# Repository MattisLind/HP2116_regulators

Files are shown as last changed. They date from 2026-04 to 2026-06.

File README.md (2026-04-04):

# HP2116_regulators
A project to create replicas of the two voltage regulator boards of the HP2116.

Unfortunately my HP 2116B which I was able to rescue from destruction in the fall of 2025 was missing not just two logic boards (of which one I was able to buy on Ebay later) but also two very important small regulator boards. The purpose of these two boards is to control the generation of all the voltages needed by the computer.

Missing regulators

Finding the exact boards will probably take quite long time if at all possible.

A fellow collector took photos of the boards in his HP 2116C machine. They are very similar except for the memorys regulator not supplying a 32V so those components are not populated.

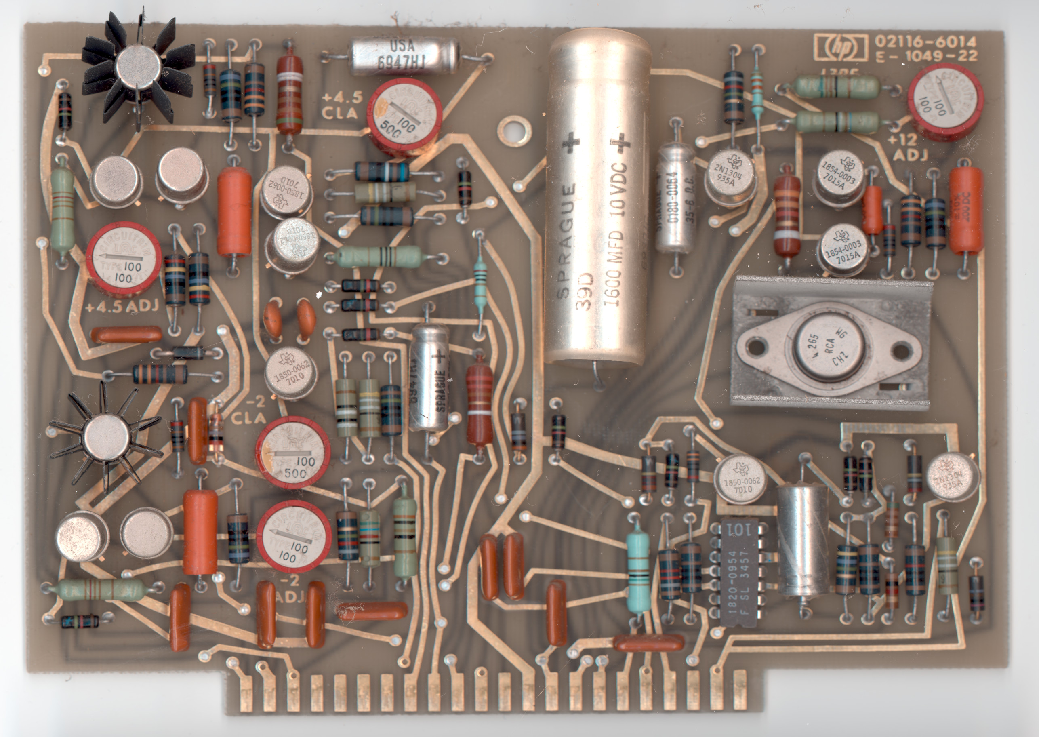
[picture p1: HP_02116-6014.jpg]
Logic regulator

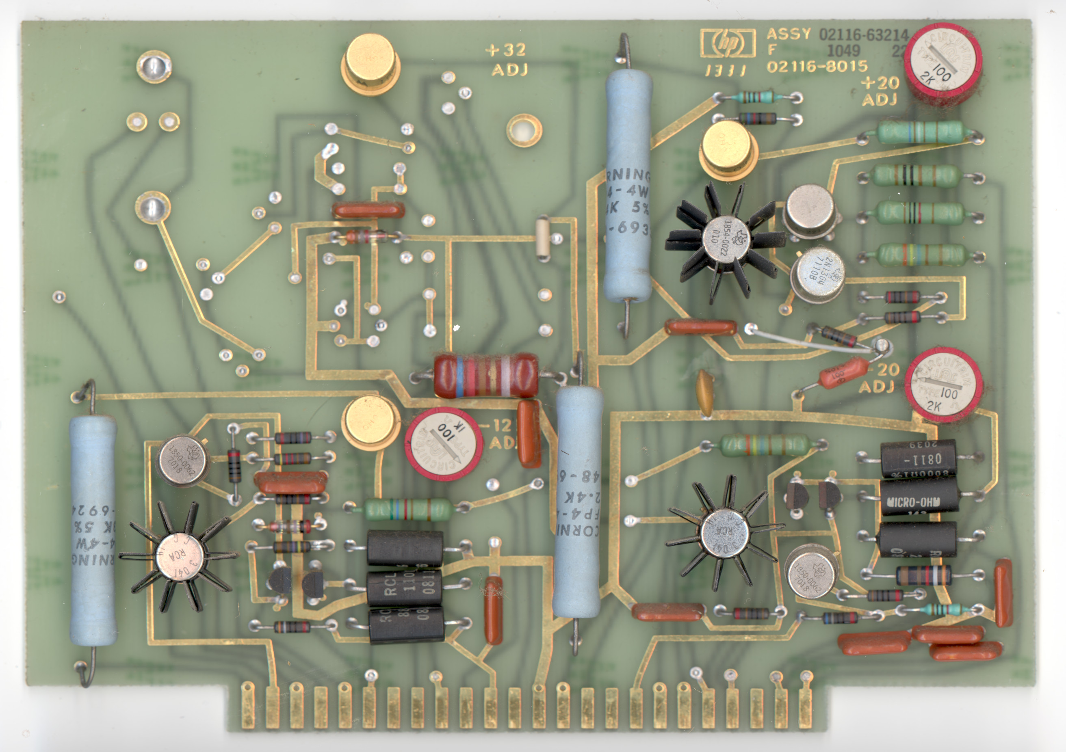
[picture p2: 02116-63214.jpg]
Memory regulator


He also took some measurements of the boards

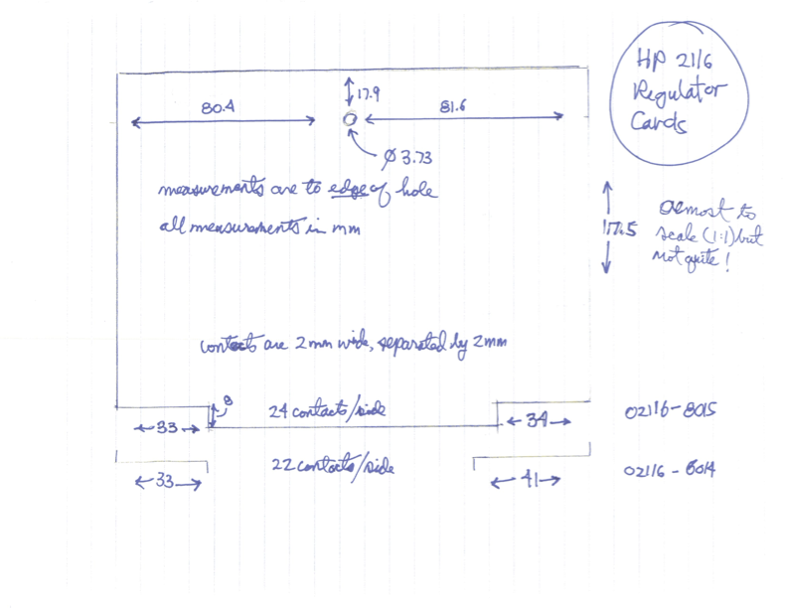
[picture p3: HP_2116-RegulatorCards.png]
Measurments


Thank you Jack! With this I will be able to create boards that fit the machine correctly.

I will be facing a number of problems when doing this. For example there are extensive use of really old Germanium transistors used. The reason for this is partly because of the low Vbe forward voltage. These transistors are used in the current sense circuit basically sitting with the B and E over the current sense resistor. The start to conduct over 0.2V and thus limiting or shutting down the power supply if there are excess current. This circuit with these specifcations wouldn't work with Silicon transistors.

Then the Logic Regulator board are using the Fairchild CTL chip family for logic functions and sequencing of the voltages in the power supply. I thought about replacing it with a corresponding TTL circuit but then the problem is that I don't really now how the TTL circuit react when low voltages are used. I.e. when the power supply is starting up. CTL is basically emitter coupled logic and I came to the conclusion that it would be possible to replicate the functionality using discrete NPN and PNP transistors. Tieing together the emitters of PNP transistors creates AND gates while tieing togther emitters of NPN transistors creates OR gates.

I simulated this design in LTSpice and came to the conclusion that it will likely work as the original circuit using the integrated CTL chip.

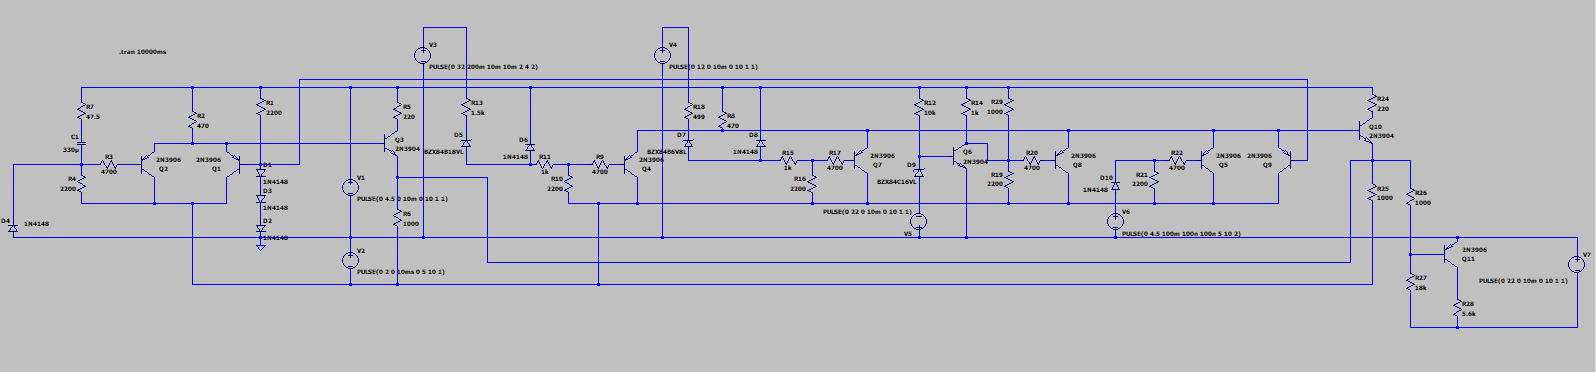
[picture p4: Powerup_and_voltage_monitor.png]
LTSpice simulation


The waveforms of the power monitor

Green is the simulated +32V. Delayed and then goes out after about 2 seconds. Blue is the +12V that power up slowly. Red is the even slower -22V. The cyan signal is the 4.5V PSO signal that tells is there is a overheating condition. The resulting signal is the violet. It enables the -12V regulator when low and shuts it down when grounded. It looks like the logic is working.

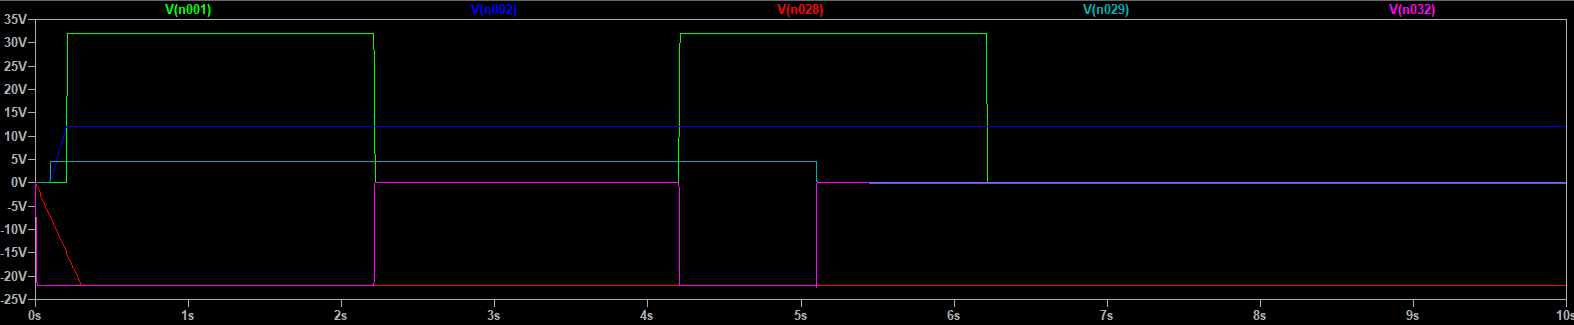
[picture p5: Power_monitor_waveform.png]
Waveforms


In the picture below green is the signal to the -12V supply and the blue is the 4.5V power line.

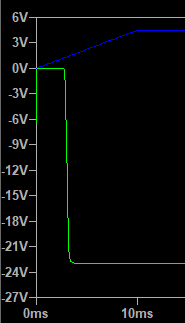
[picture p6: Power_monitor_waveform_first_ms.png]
Waveforms first few milliseconds


Here is the schematic for the logic regulator.

Logic regulator schematic

And this is the memory regulator schematic.

Memory regulator schematic

At this point I have started to procure components. I managed to find the 2N1304 and 2N1305 germanium transistors from a vendor in the UK and the same company also had the 2N4044 matched pairs so now all the small resistors, zeners and caps need to be ordered and then I can start laying out the PCB. Care has to be taken so there is room for the heatsinks on the TO5. Both boards have a TO66 power transistor where the exact match is hard to find. I think a NPN TIP41 should be just fine since this just a simple emitter follower output stage to increase the drive power.

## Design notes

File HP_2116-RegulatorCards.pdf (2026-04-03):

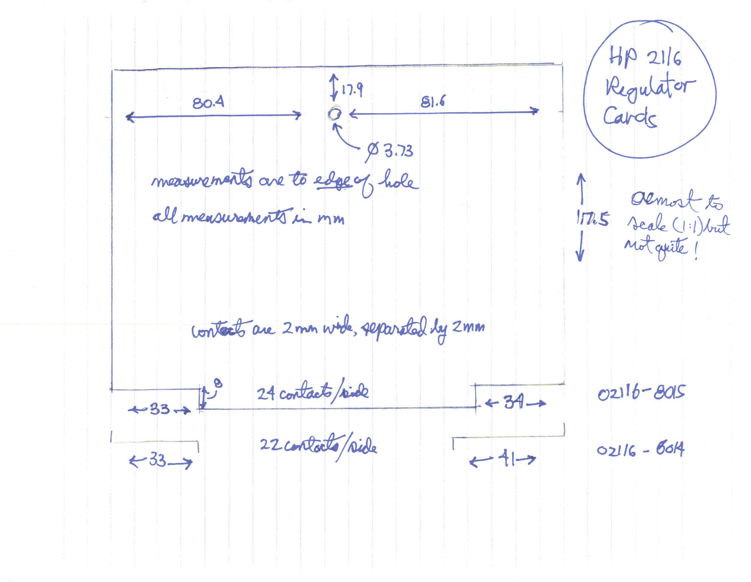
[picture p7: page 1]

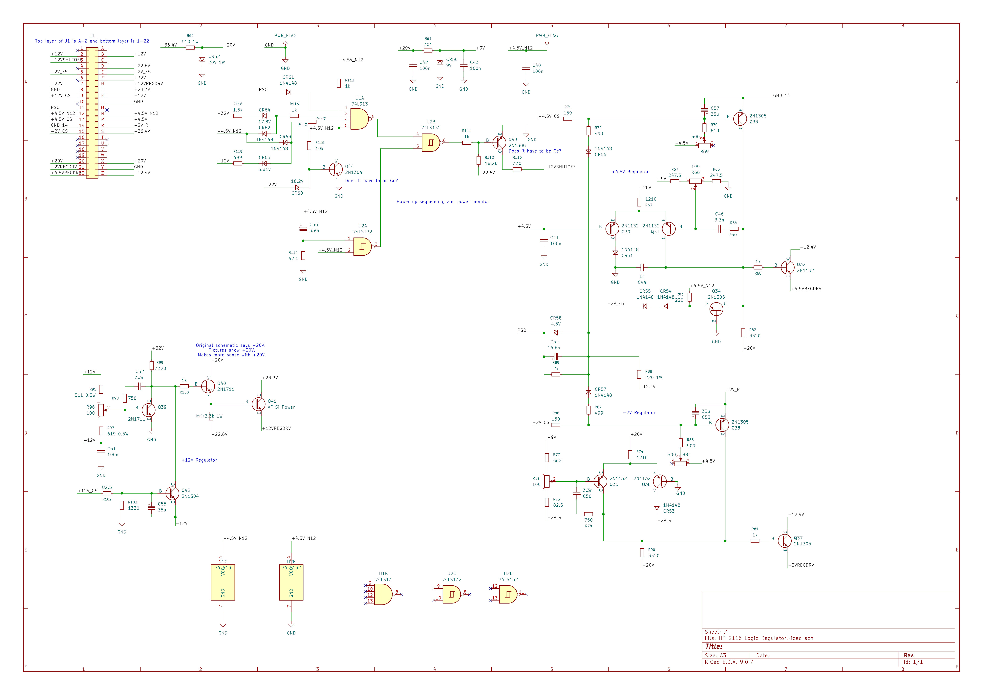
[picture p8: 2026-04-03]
HP_2116_Logic_Regulator/HP_2116_Logic_Regulator.jpg

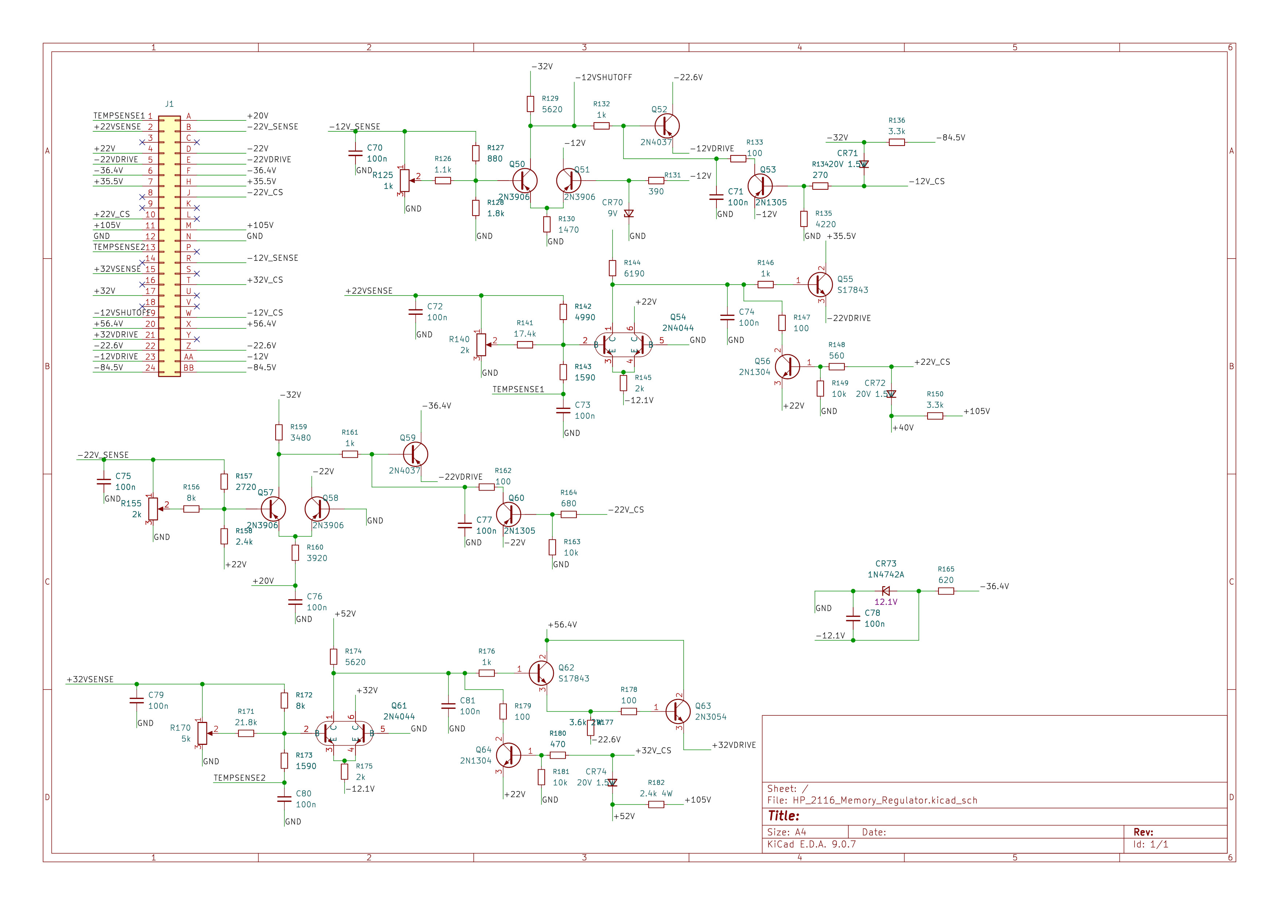
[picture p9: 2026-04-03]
HP_2116_Memory_Regulator/HP_2116_Memory_Regulator.jpg

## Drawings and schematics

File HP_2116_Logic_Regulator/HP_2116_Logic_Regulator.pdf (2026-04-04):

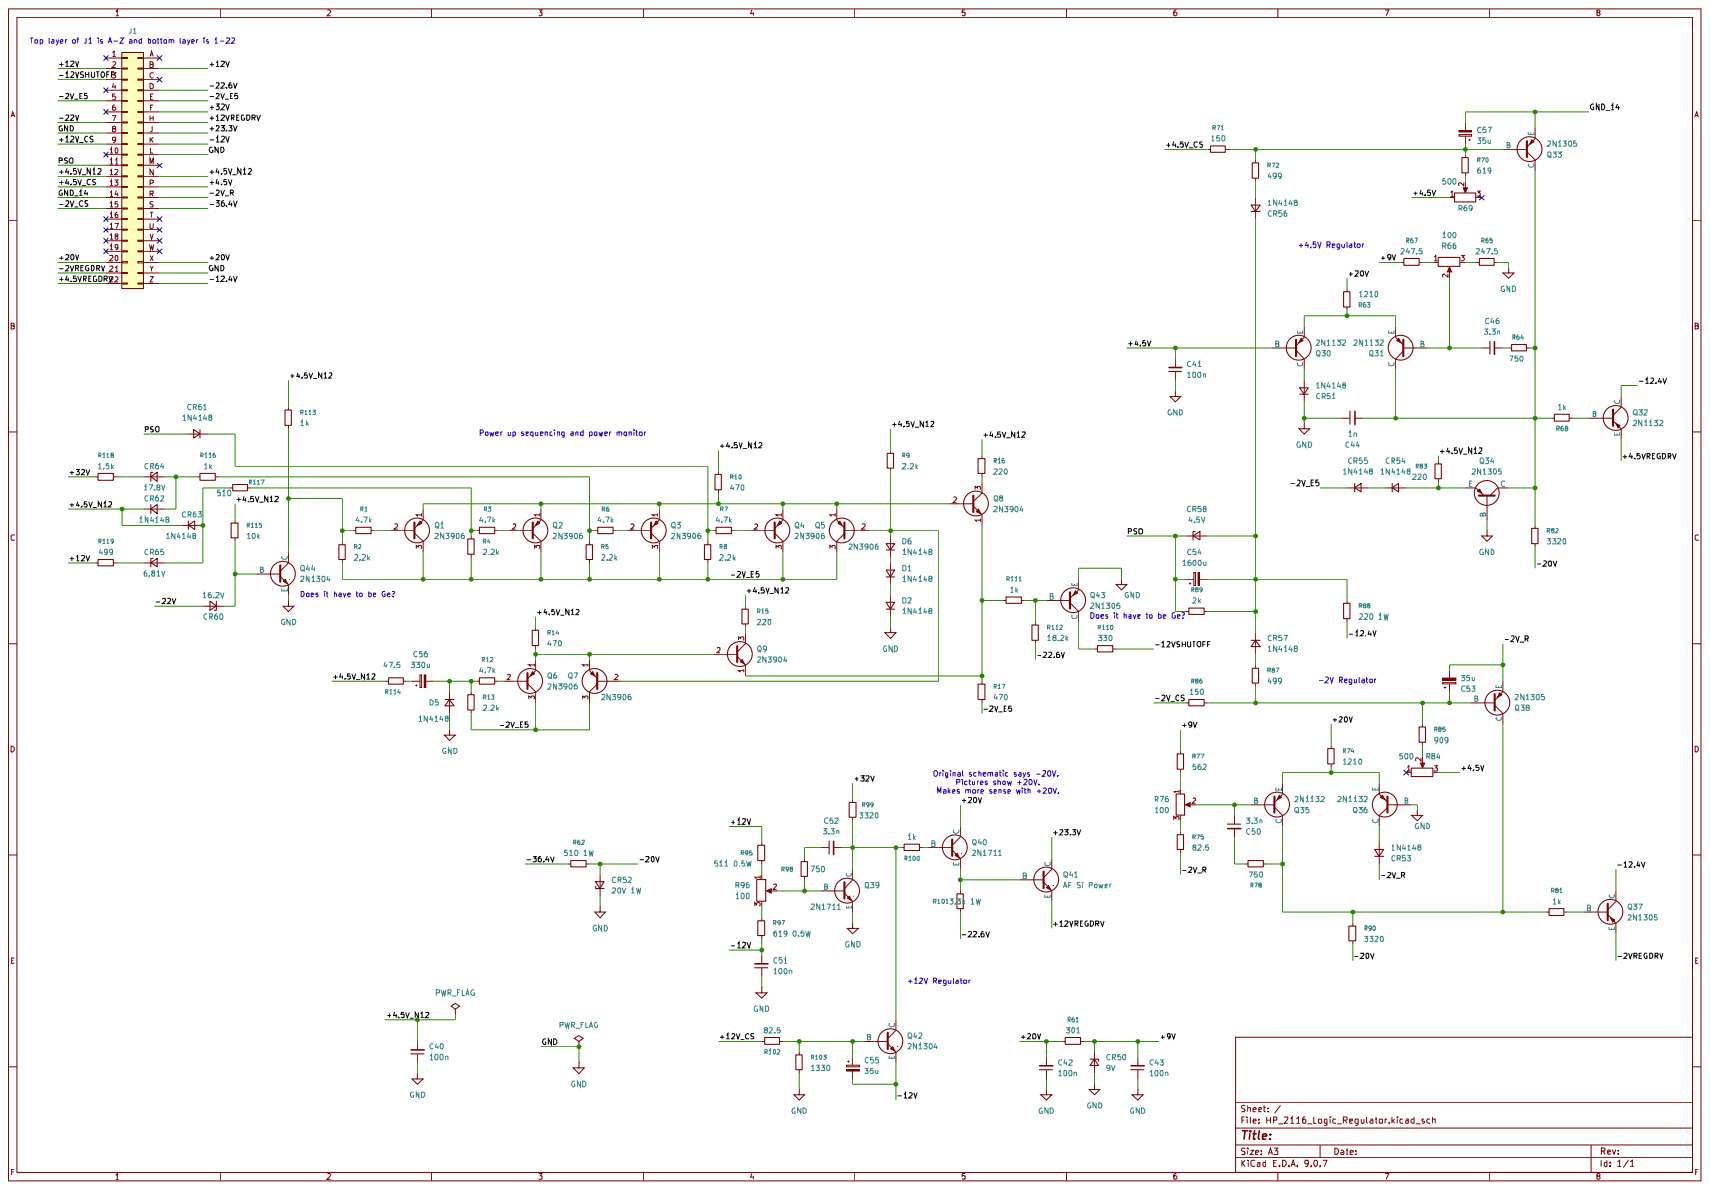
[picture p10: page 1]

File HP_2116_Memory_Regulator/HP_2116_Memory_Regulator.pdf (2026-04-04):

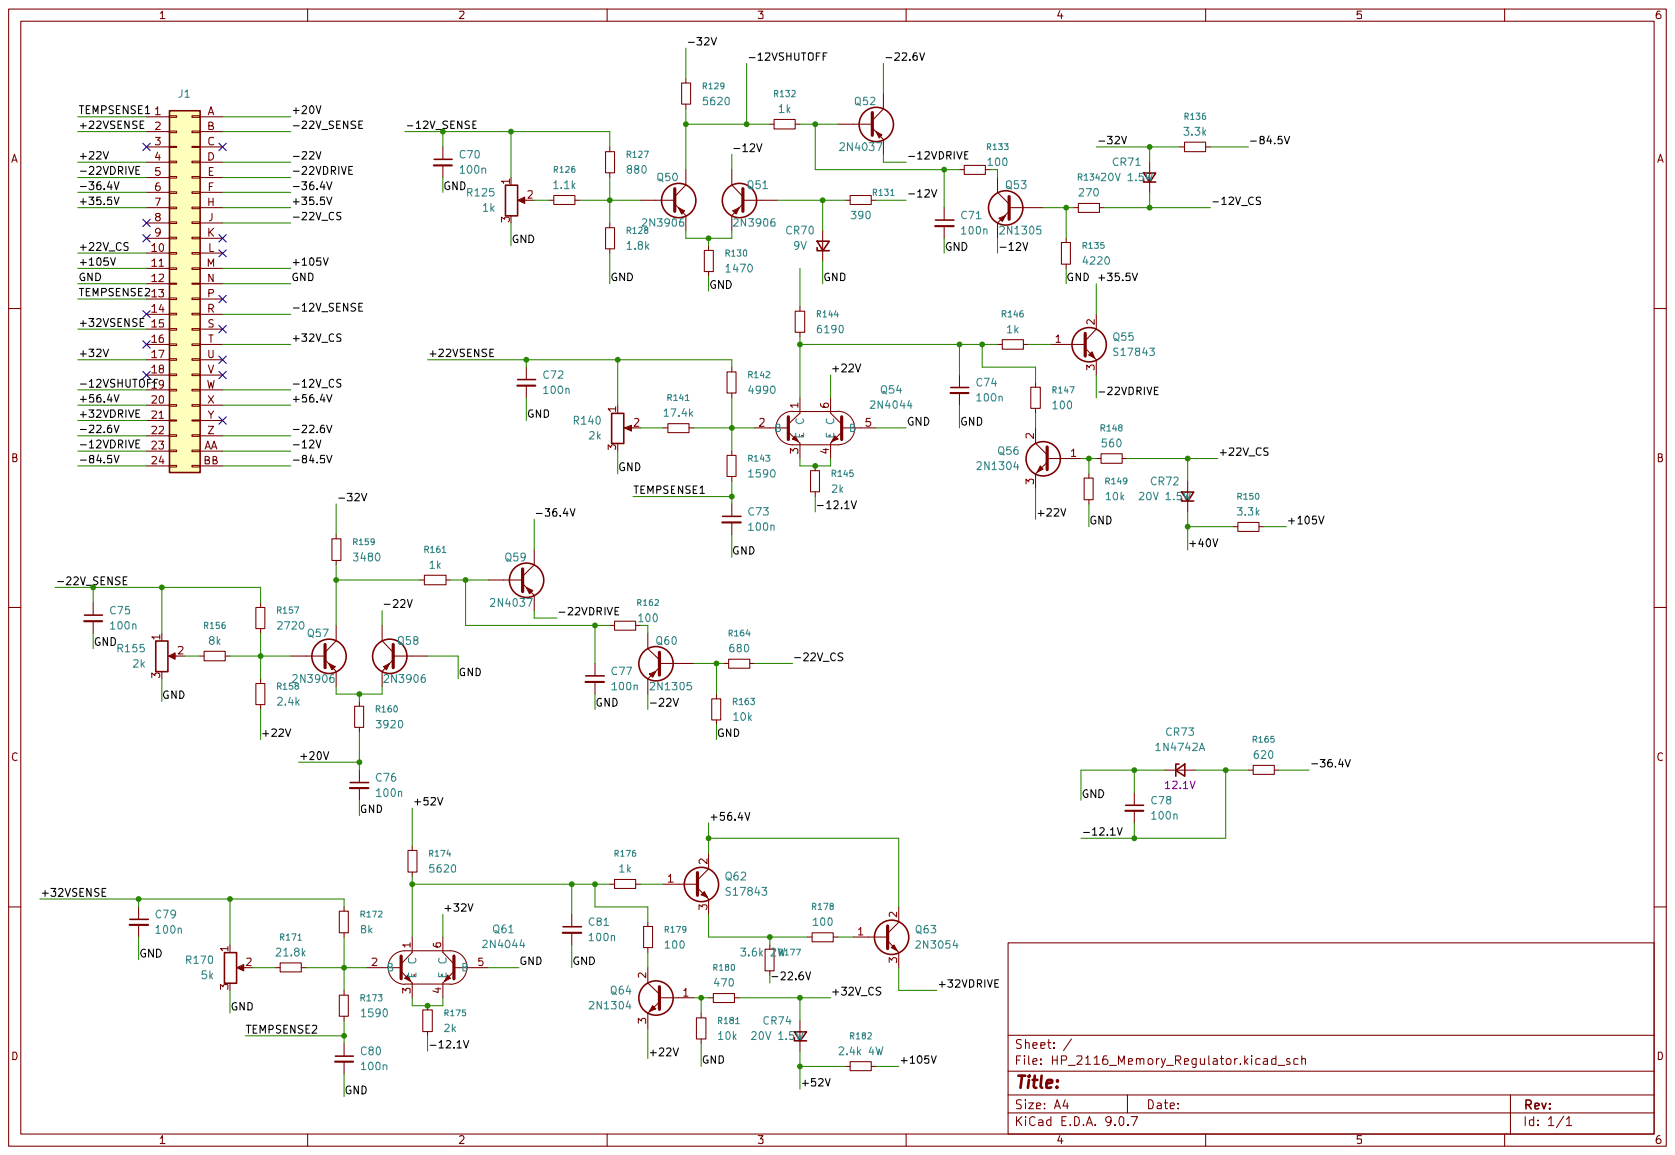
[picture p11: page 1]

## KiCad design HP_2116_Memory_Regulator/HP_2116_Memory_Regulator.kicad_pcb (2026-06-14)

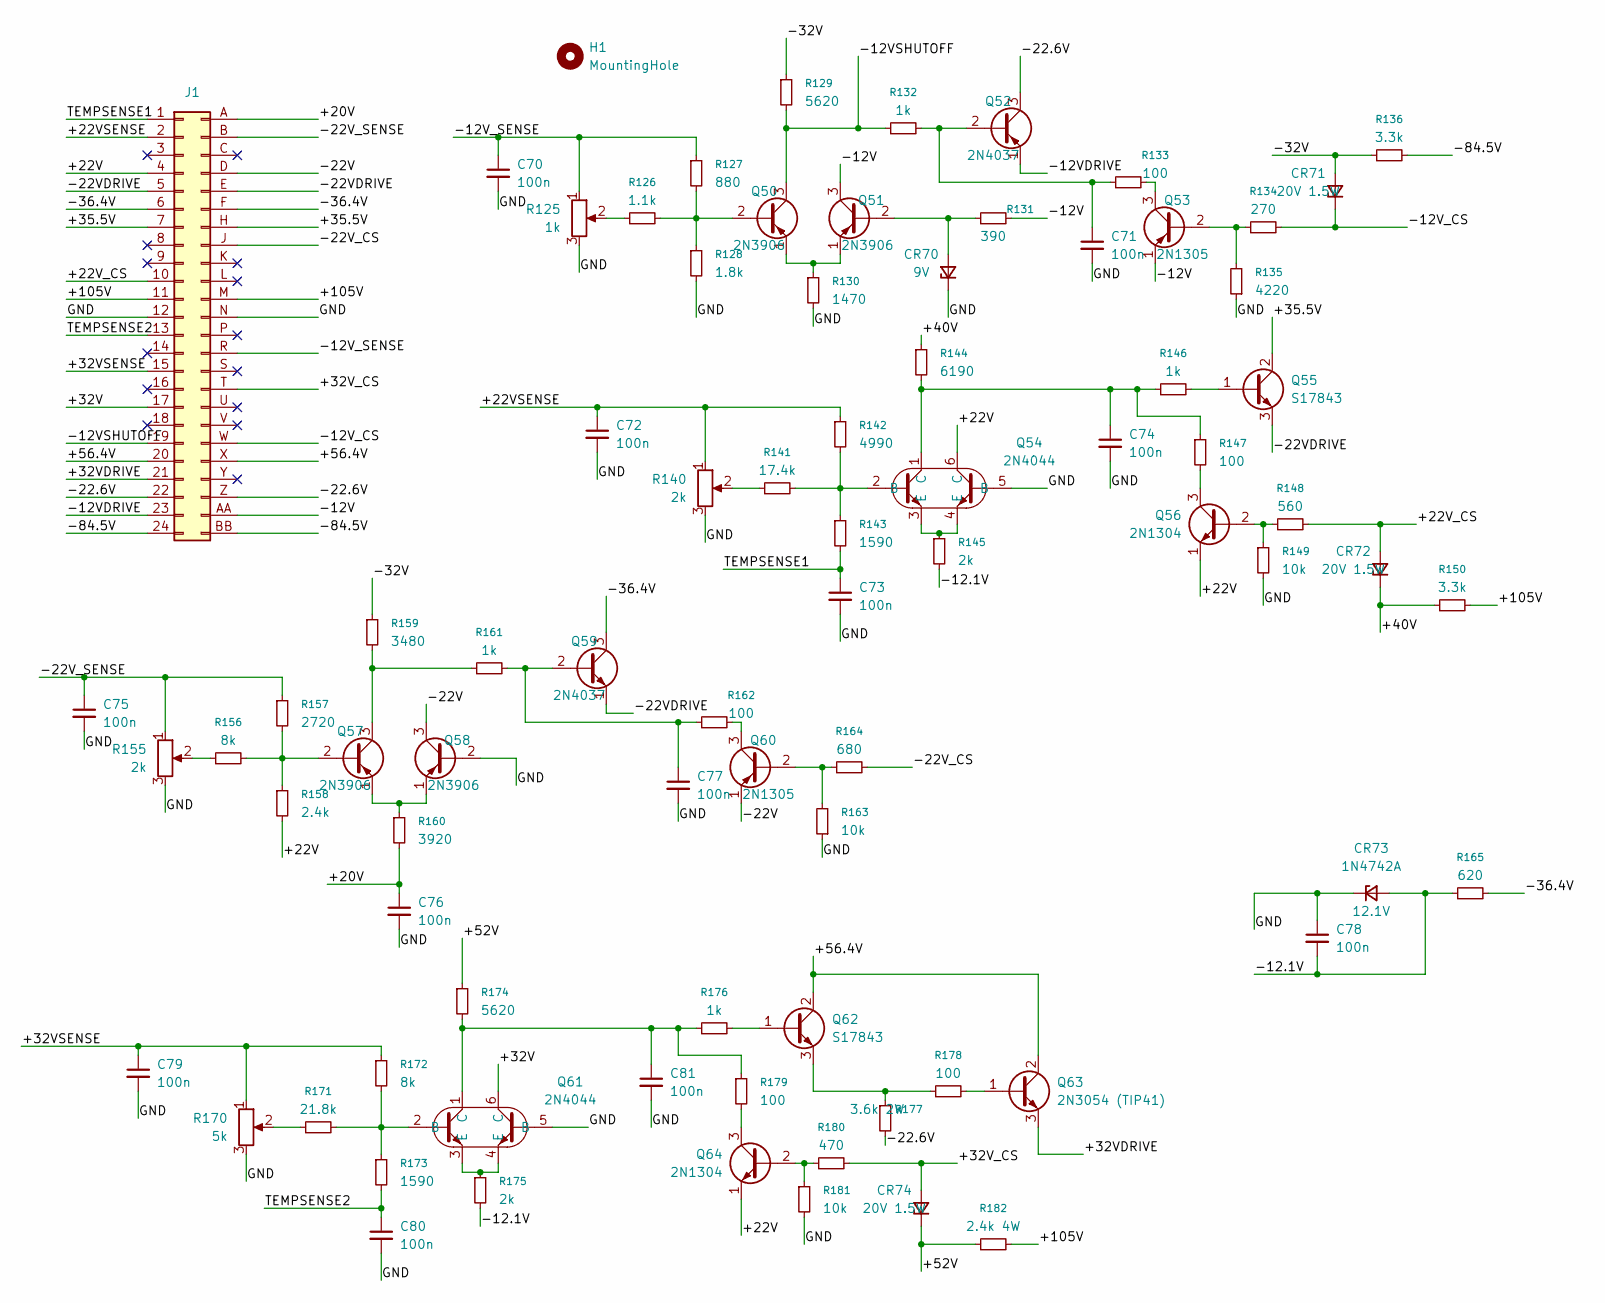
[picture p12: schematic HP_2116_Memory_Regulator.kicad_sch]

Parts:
C70, C71, C72, C73, C74, C75, C76, C77, C78, C79, C80, C81: 100n; C_Disc_D4.3mm_W1.9mm_P5.00mm
CR70: 9V; D_DO-41_SOD81_P10.16mm_Horizontal
CR71, CR72, CR74: 20V 1.5W; D_DO-41_SOD81_P10.16mm_Horizontal
CR73: 1N4742A; D_DO-41_SOD81_P10.16mm_Horizontal
H1: MountingHole; MountingHole_3.7mm
J1: Untitled
Q50, Q51, Q57, Q58: 2N3906; TO-92_Inline
Q52, Q59: 2N4037; TO-5-3
Q53, Q60: 2N1305; TO-5-3
Q54, Q61: 2N4044; TO-78-6
Q55, Q62: S17843; TO-5-3
Q56, Q64: 2N1304; TO-5-3
Q63: 2N3054 (TIP41); TO-220-3_Horizontal_TabDown
R125: 1k; Potentiometer_Bourns_3266W_Vertical
R126: 1.1k; R_Axial_DIN0207_L6.3mm_D2.5mm_P10.16mm_Horizontal
R127: 880; R_Axial_DIN0207_L6.3mm_D2.5mm_P10.16mm_Horizontal
R128: 1.8k; R_Axial_DIN0207_L6.3mm_D2.5mm_P10.16mm_Horizontal
R129, R174: 5620; R_Axial_DIN0207_L6.3mm_D2.5mm_P10.16mm_Horizontal
R130: 1470; R_Axial_DIN0207_L6.3mm_D2.5mm_P10.16mm_Horizontal
R131: 390; R_Axial_DIN0207_L6.3mm_D2.5mm_P10.16mm_Horizontal
R132, R146, R161, R176: 1k; R_Axial_DIN0207_L6.3mm_D2.5mm_P10.16mm_Horizontal
R133, R147, R162, R178, R179: 100; R_Axial_DIN0207_L6.3mm_D2.5mm_P10.16mm_Horizontal
R134: 270; R_Axial_DIN0207_L6.3mm_D2.5mm_P10.16mm_Horizontal
R135: 4220; R_Axial_DIN0207_L6.3mm_D2.5mm_P10.16mm_Horizontal
R136, R150: 3.3k; R_Axial_DIN0414_L11.9mm_D4.5mm_P15.24mm_Horizontal
R140, R155: 2k; Potentiometer_Bourns_3266W_Vertical
R141: 17.4k; R_Axial_DIN0207_L6.3mm_D2.5mm_P10.16mm_Horizontal
R142: 4990; R_Axial_DIN0207_L6.3mm_D2.5mm_P10.16mm_Horizontal
R143, R173: 1590; R_Axial_DIN0207_L6.3mm_D2.5mm_P10.16mm_Horizontal
R144: 6190; R_Axial_DIN0207_L6.3mm_D2.5mm_P10.16mm_Horizontal
R145, R175: 2k; R_Axial_DIN0207_L6.3mm_D2.5mm_P10.16mm_Horizontal
R148: 560; R_Axial_DIN0207_L6.3mm_D2.5mm_P10.16mm_Horizontal
R149, R163, R181: 10k; R_Axial_DIN0207_L6.3mm_D2.5mm_P10.16mm_Horizontal
R156, R172: 8k; R_Axial_DIN0207_L6.3mm_D2.5mm_P10.16mm_Horizontal
R157: 2720; R_Axial_DIN0207_L6.3mm_D2.5mm_P10.16mm_Horizontal
R158: 2.4k; R_Axial_DIN0207_L6.3mm_D2.5mm_P10.16mm_Horizontal
R159: 3480; R_Axial_DIN0207_L6.3mm_D2.5mm_P10.16mm_Horizontal
R160: 3920; R_Axial_DIN0207_L6.3mm_D2.5mm_P10.16mm_Horizontal
R164: 680; R_Axial_DIN0207_L6.3mm_D2.5mm_P10.16mm_Horizontal
R165: 620; R_Axial_DIN0414_L11.9mm_D4.5mm_P15.24mm_Horizontal
R170: 5k; Potentiometer_Bourns_3266W_Vertical
R171: 21.8k; R_Axial_DIN0207_L6.3mm_D2.5mm_P10.16mm_Horizontal
R177: 3.6k 2W; R_Axial_DIN0207_L6.3mm_D2.5mm_P10.16mm_Horizontal
R180: 470; R_Axial_DIN0207_L6.3mm_D2.5mm_P10.16mm_Horizontal
R182: 2.4k 4W; R_Axial_DIN0414_L11.9mm_D4.5mm_P25.40mm_Horizontal

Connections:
/+20V: C76.1, J1.A, R160.2
/+22V: J1.4, Q54.6 (C), Q56.1 (E), Q64.1 (E), R158.2
/+22VSENSE: C72.1, J1.2, R140.1, R142.1
/+22V_CS: CR72.2 (A), J1.10, R148.2
/+32V: J1.17, Q61.6 (C)
/+32VDRIVE: J1.21, Q63.3 (E)
/+32VSENSE: C79.1, J1.15, R170.1, R172.1
/+32V_CS: CR74.2 (A), J1.T, R180.2
/+35.5V: J1.7, J1.H, Q55.2 (C)
/+40V: CR72.1 (K), R144.1, R150.1
/+52V: CR74.1 (K), R174.1, R182.1
/+56.4V: J1.20, J1.X, Q62.2 (C), Q63.2 (C)
/+105V: J1.11, J1.M, R150.2, R182.2
/-12.1V: C78.2, CR73.2 (A), R145.2, R165.1, R175.2
/-12V: J1.AA, Q51.3 (C), Q53.1 (E), R131.2
/-12VDRIVE: J1.23, Q52.1 (E)
/-12VSHUTOFF: J1.19, Q50.3 (C), R129.2, R132.1
/-12V_CS: CR71.1 (K), J1.W, R134.2
/-12V_SENSE: C70.1, J1.R, R125.1, R127.1
/-22.6V: J1.22, J1.Z, Q52.3 (C), R177.2
/-22V: J1.D, Q58.3 (C), Q60.1 (E)
/-22VDRIVE: J1.5, J1.E, Q55.3 (E), Q59.1 (E)
/-22V_CS: J1.J, R164.2
/-22V_SENSE: C75.1, J1.B, R155.1, R157.1
/-32V: CR71.2 (A), R129.1, R136.1, R159.1
/-36.4V: J1.6, J1.F, Q59.3 (C), R165.2
/-84.5V: J1.24, J1.BB, R136.2
/GND: C70.2, C71.2, C72.2, C73.2, C74.2, C75.2, C76.2, C77.2, C78.1, C79.2, C80.2, C81.2, CR70.1 (K), CR73.1 (K), J1.12, J1.N, Q54.5 (B), Q58.2 (B), Q61.5 (B), R125.3, R128.2, R130.2, R135.1, R140.3, R149.2, R155.3, R163.1, R170.3, R181.2
/TEMPSENSE1: C73.1, J1.1, R143.2
/TEMPSENSE2: C80.1, J1.13, R173.2
unnamed: C74.1, Q54.1 (C), R144.2, R146.1, R147.1
unnamed: C81.1, Q61.1 (C), R174.2, R176.1, R179.1
unnamed: CR70.2 (A), Q51.2 (B), R131.1
unnamed: Q50.2 (B), R126.2, R127.2, R128.1
unnamed: Q50.1 (E), Q51.1 (E), R130.1
unnamed: C71.1, Q52.2 (B), R132.2, R133.1
unnamed: Q53.2 (B), R134.1, R135.2
unnamed: Q53.3 (C), R133.2
unnamed: Q54.2 (B), R141.2, R142.2, R143.1
unnamed: Q54.3 (E), Q54.4 (E), R145.1
unnamed: Q55.1 (B), R146.2
unnamed: Q56.2 (B), R148.1, R149.1
unnamed: Q56.3 (C), R147.2
unnamed: Q57.2 (B), R156.2, R157.2, R158.1
unnamed: Q57.3 (C), R159.2, R161.1
unnamed: Q57.1 (E), Q58.1 (E), R160.1
unnamed: C77.1, Q59.2 (B), R161.2, R162.1
unnamed: Q60.2 (B), R163.2, R164.1
unnamed: Q60.3 (C), R162.2
unnamed: Q61.2 (B), R171.2, R172.2, R173.1
unnamed: Q61.3 (E), Q61.4 (E), R175.1
unnamed: Q62.1 (B), R176.2
unnamed: Q62.3 (E), R177.1, R178.1
unnamed: Q63.1 (B), R178.2
unnamed: Q64.2 (B), R180.1, R181.1
unnamed: Q64.3 (C), R179.2
unnamed: R125.2, R126.1
unnamed: R140.2, R141.1
unnamed: R155.2, R156.1
unnamed: R170.2, R171.1

Board: 2 copper layers, 81 parts (0 on the bottom side), 60 nets, no tracks yet.

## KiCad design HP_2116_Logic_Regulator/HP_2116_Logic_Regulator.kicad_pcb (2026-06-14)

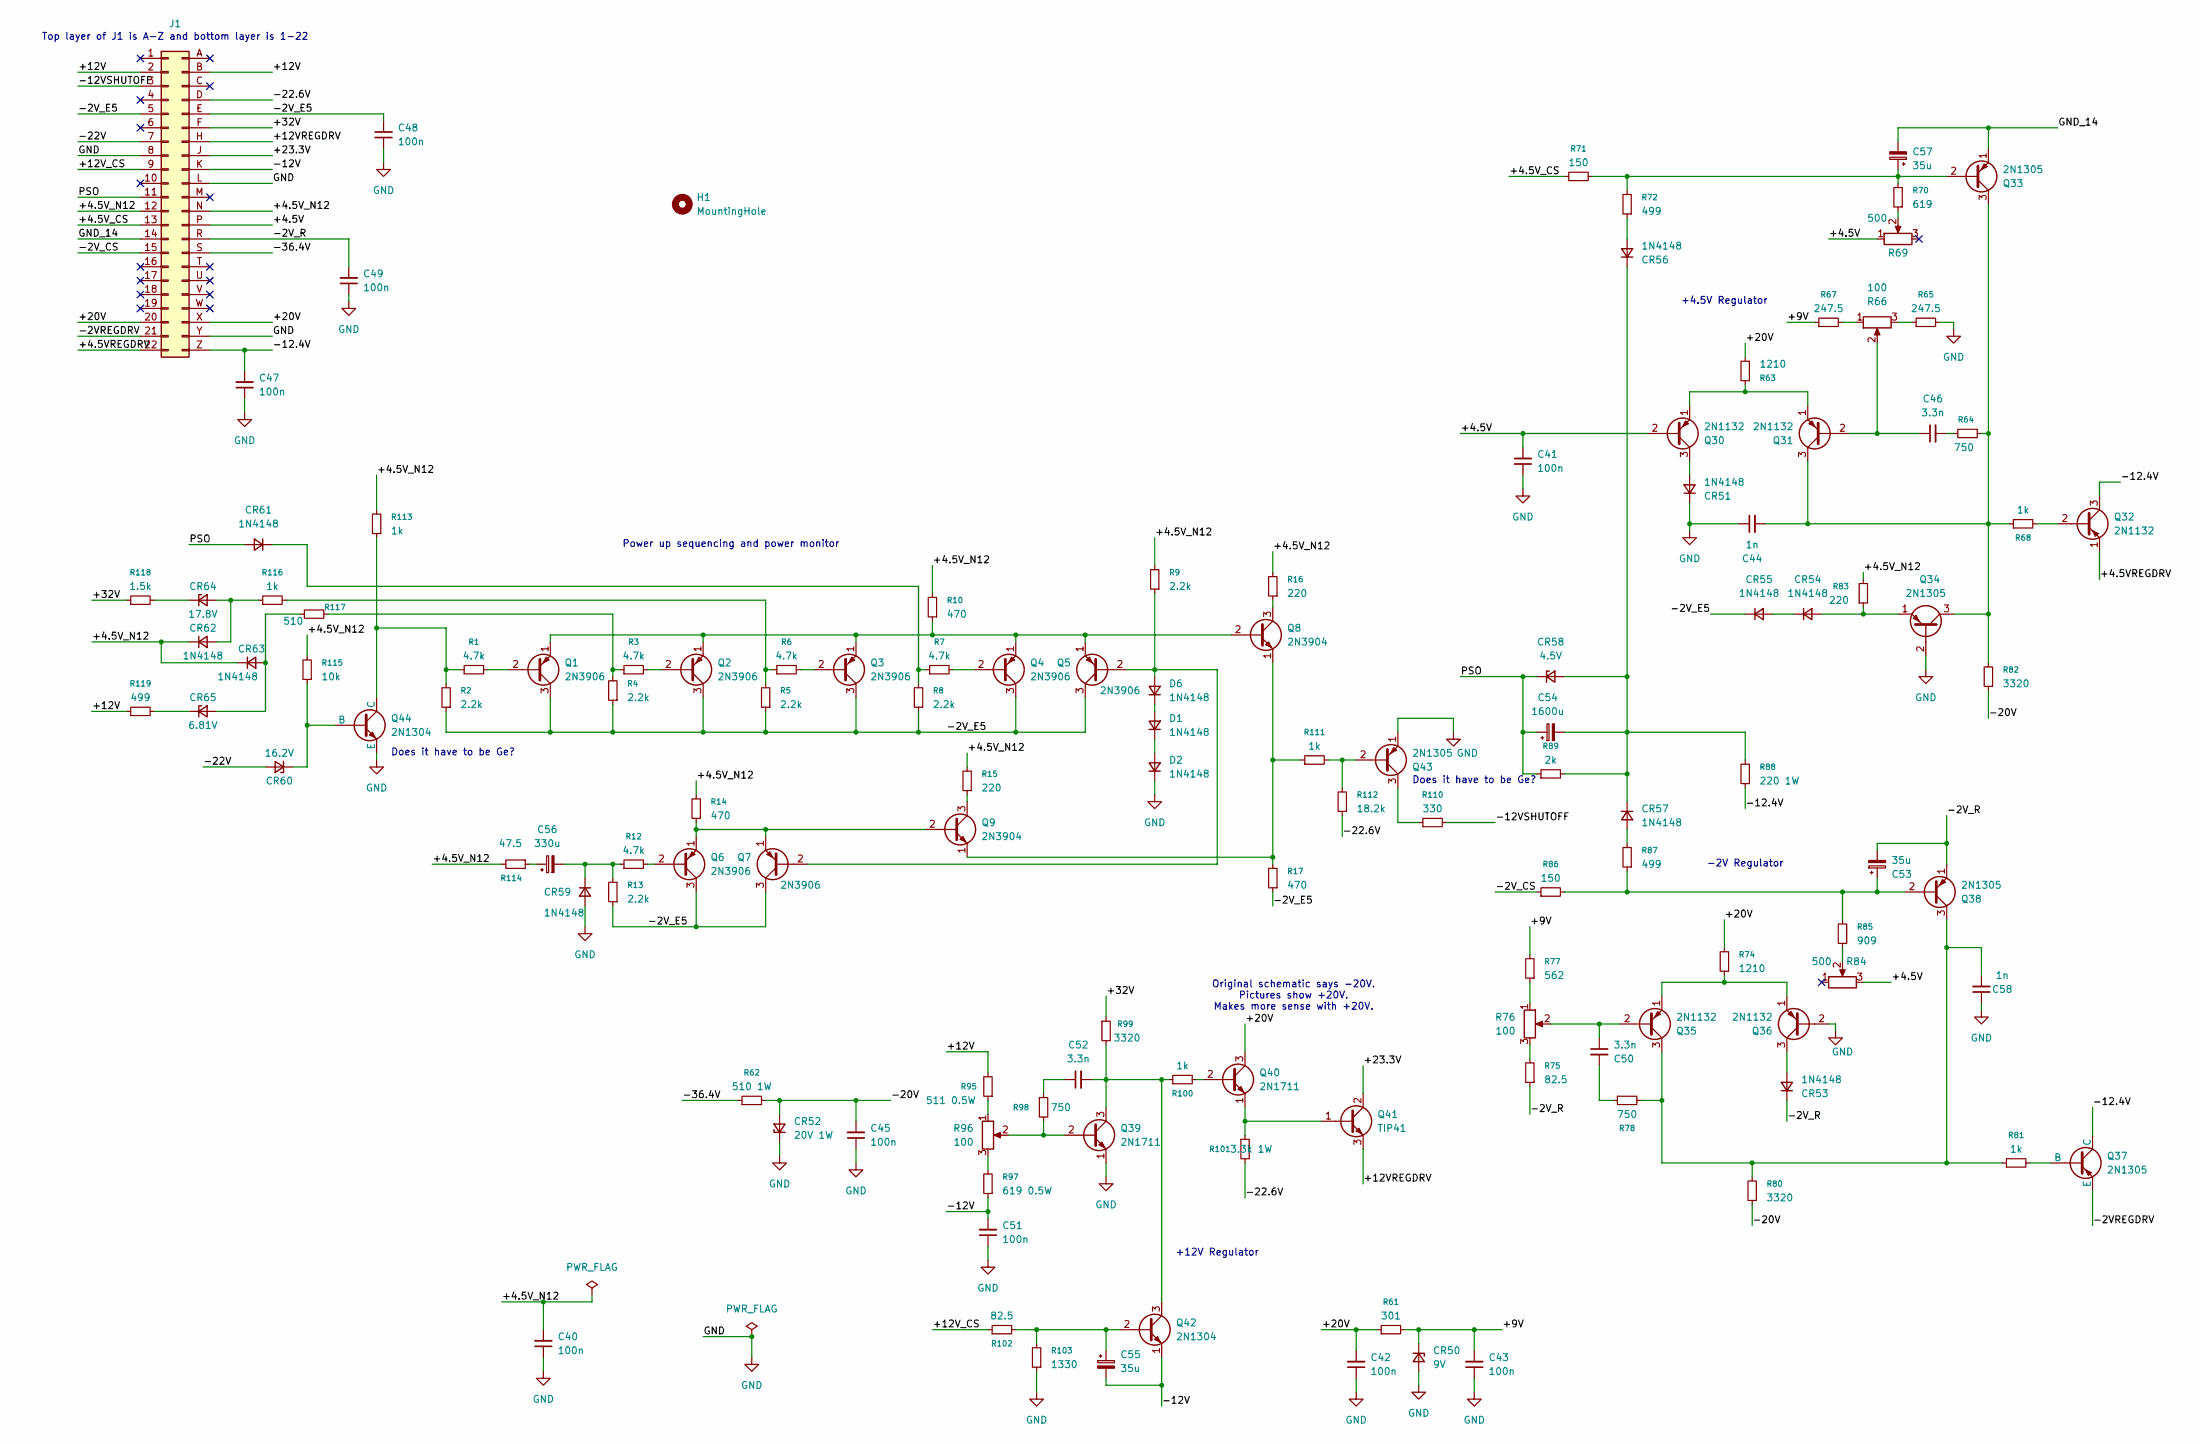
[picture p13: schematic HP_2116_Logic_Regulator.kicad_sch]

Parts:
C40, C41, C42, C43, C45, C47, C48, C49, C51: 100n; C_Disc_D4.3mm_W1.9mm_P5.00mm
C44, C58: 1n; C_Disc_D4.3mm_W1.9mm_P5.00mm
C46, C50, C52: 3.3n; C_Disc_D4.3mm_W1.9mm_P5.00mm
C53, C55, C57: 35u; CP_Radial_D5.0mm_P2.00mm
C54: 1600u; CP_Radial_D16.0mm_P7.50mm
C56: 330u; CP_Radial_D6.3mm_P2.50mm
CR50: 9V; D_DO-41_SOD81_P10.16mm_Horizontal
CR51, CR53, CR54, CR55, CR56, CR57, CR59, CR61, CR62, CR63: 1N4148; D_DO-35_SOD27_P10.16mm_Horizontal
CR52: 20V 1W; D_DO-41_SOD81_P10.16mm_Horizontal
CR58: 4.5V; D_DO-35_SOD27_P10.16mm_Horizontal
CR60: 16.2V; D_DO-35_SOD27_P10.16mm_Horizontal
CR64: 17.8V; D_DO-35_SOD27_P10.16mm_Horizontal
CR65: 6.81V; D_DO-35_SOD27_P10.16mm_Horizontal
D1, D2, D6: 1N4148; D_DO-35_SOD27_P10.16mm_Horizontal
H1: MountingHole; MountingHole_3.7mm
J1: 22 Pin HP EDAC
Q1, Q2, Q3, Q4, Q5, Q6, Q7: 2N3906; TO-92_Inline
Q8, Q9: 2N3904; TO-92_Inline
Q30, Q31, Q32, Q35, Q36: 2N1132; TO-5-3
Q33, Q34, Q37, Q38, Q43: 2N1305; TO-5-3
Q39, Q40: 2N1711; TO-5-3
Q41: TIP41; TO-220-3_Horizontal_TabDown
Q42, Q44: 2N1304; TO-5-3
R1, R3, R6, R7, R12: 4.7k; R_Axial_DIN0207_L6.3mm_D2.5mm_P10.16mm_Horizontal
R2, R4, R5, R8, R9, R13: 2.2k; R_Axial_DIN0207_L6.3mm_D2.5mm_P10.16mm_Horizontal
R10, R14, R17: 470; R_Axial_DIN0207_L6.3mm_D2.5mm_P10.16mm_Horizontal
R15, R16, R83: 220; R_Axial_DIN0207_L6.3mm_D2.5mm_P10.16mm_Horizontal
R61: 301; R_Axial_DIN0207_L6.3mm_D2.5mm_P10.16mm_Horizontal
R62: 510 1W; R_Axial_DIN0414_L11.9mm_D4.5mm_P20.32mm_Horizontal
R63, R74: 1210; R_Axial_DIN0207_L6.3mm_D2.5mm_P10.16mm_Horizontal
R64, R78, R98: 750; R_Axial_DIN0207_L6.3mm_D2.5mm_P10.16mm_Horizontal
R65, R67: 247.5; R_Axial_DIN0207_L6.3mm_D2.5mm_P10.16mm_Horizontal
R66, R76, R96: 100; Potentiometer_Bourns_3266W_Vertical
R68, R81, R100, R111, R113, R116: 1k; R_Axial_DIN0207_L6.3mm_D2.5mm_P10.16mm_Horizontal
R69, R84: 500; Potentiometer_Bourns_3266W_Vertical
R70: 619; R_Axial_DIN0207_L6.3mm_D2.5mm_P10.16mm_Horizontal
R71, R86: 150; R_Axial_DIN0207_L6.3mm_D2.5mm_P10.16mm_Horizontal
R72, R87, R119: 499; R_Axial_DIN0207_L6.3mm_D2.5mm_P10.16mm_Horizontal
R75, R102: 82.5; R_Axial_DIN0207_L6.3mm_D2.5mm_P10.16mm_Horizontal
R77: 562; R_Axial_DIN0207_L6.3mm_D2.5mm_P10.16mm_Horizontal
R80, R82, R99: 3320; R_Axial_DIN0207_L6.3mm_D2.5mm_P10.16mm_Horizontal
R85: 909; R_Axial_DIN0207_L6.3mm_D2.5mm_P10.16mm_Horizontal
R88: 220 1W; R_Axial_DIN0414_L11.9mm_D4.5mm_P20.32mm_Horizontal
R89: 2k; R_Axial_DIN0207_L6.3mm_D2.5mm_P10.16mm_Horizontal
R95: 511 0.5W; R_Axial_DIN0309_L9.0mm_D3.2mm_P15.24mm_Horizontal
R97: 619 0.5W; R_Axial_DIN0309_L9.0mm_D3.2mm_P15.24mm_Horizontal
R101: 3.3k 1W; R_Axial_DIN0414_L11.9mm_D4.5mm_P20.32mm_Horizontal
R103: 1330; R_Axial_DIN0207_L6.3mm_D2.5mm_P10.16mm_Horizontal
R110: 330; R_Axial_DIN0207_L6.3mm_D2.5mm_P10.16mm_Horizontal
R112: 18.2k; R_Axial_DIN0207_L6.3mm_D2.5mm_P10.16mm_Horizontal
R114: 47.5; R_Axial_DIN0207_L6.3mm_D2.5mm_P10.16mm_Horizontal
R115: 10k; R_Axial_DIN0207_L6.3mm_D2.5mm_P10.16mm_Horizontal
R117: 510; R_Axial_DIN0207_L6.3mm_D2.5mm_P10.16mm_Horizontal
R118: 1.5k; R_Axial_DIN0207_L6.3mm_D2.5mm_P10.16mm_Horizontal

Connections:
/+4.5V: C41.2, J1.P, Q30.2 (B), R69.1, R84.3
/+4.5VREGDRV: J1.22, Q32.1 (E)
/+4.5V_CS: J1.13, R71.1
/+4.5V_N12: C40.2, CR62.1 (K), CR63.1 (K), J1.12, J1.N, R9.2, R10.2, R14.2, R15.2, R16.2, R83.2, R113.2, R114.2, R115.2
/+9V: C43.2, CR50.1 (K), R61.2, R67.1, R77.2
/+12V: J1.2, J1.B, R95.2, R119.1
/+12VREGDRV: J1.H, Q41.3 (E)
/+12V_CS: J1.9, R102.1
/+20V: C42.2, J1.20, J1.X, Q40.3 (C), R61.1, R63.1, R74.2
/+23.3V: J1.J, Q41.2 (C)
/+32V: J1.F, R99.1, R118.1
/-2VREGDRV: J1.21, Q37.3 (E)
/-2V_CS: J1.15, R86.1
/-2V_E5: C48.2, CR55.1 (K), J1.5, J1.E, Q1.3 (C), Q2.3 (C), Q3.3 (C), Q4.3 (C), Q5.3 (C), Q6.3 (C), Q7.3 (C), R2.1, R4.1, R5.1, R8.1, R13.1, R17.1
/-2V_R: C49.2, C53.2, CR53.1 (K), J1.R, Q38.1 (E), R75.1
/-12.4V: C47.2, J1.Z, Q32.3 (C), Q37.1 (C), R88.1
/-12V: C51.2, C55.2, J1.K, Q42.1 (E), R97.1
/-12VSHUTOFF: J1.3, R110.2
/-20V: C45.2, CR52.2 (A), R62.2, R80.1, R82.1
/-22.6V: J1.D, R101.2, R112.1
/-22V: CR60.2 (A), J1.7
/-36.4V: J1.S, R62.1
/GND_14: C57.2, J1.14, Q33.1 (E)
/PSO: C54.1, CR58.1 (K), CR61.2 (A), J1.11, R89.1
GND: C40.1, C41.1, C42.1, C43.1, C44.1, C45.1, C47.1, C48.1, C49.1, C51.1, C58.1, CR50.2 (A), CR51.1 (K), CR52.1 (K), CR59.2 (A), D2.1 (K), J1.8, J1.L, J1.Y, Q34.2 (B), Q36.2 (B), Q39.1 (E), Q43.1 (E), Q44.3 (E), R65.2, R103.1
unnamed: C46.2, R64.2
unnamed: C50.2, R78.1
unnamed: C52.1, R98.1
unnamed: C56.1, R114.1
unnamed: CR51.2 (A), Q30.3 (C)
unnamed: CR53.2 (A), Q36.3 (C)
unnamed: CR54.2 (A), Q34.1 (E), R83.1
unnamed: CR54.1 (K), CR55.2 (A)
unnamed: CR56.2 (A), R72.1
unnamed: C54.2, CR56.1 (K), CR57.1 (K), CR58.2 (A), R88.2, R89.2
unnamed: CR57.2 (A), R87.2
unnamed: C56.2, CR59.1 (K), R12.1, R13.2
unnamed: CR60.1 (K), Q44.2 (B), R115.1
unnamed: CR61.1 (K), R7.1, R8.2
unnamed: CR62.2 (A), CR64.2 (A), R116.1
unnamed: CR63.2 (A), CR65.2 (A), R117.1
unnamed: CR64.1 (K), R118.2
unnamed: CR65.1 (K), R119.2
unnamed: D1.2 (A), D6.1 (K)
unnamed: D1.1 (K), D2.2 (A)
unnamed: D6.2 (A), Q5.2 (B), Q7.2 (B), R9.1
unnamed: Q1.2 (B), R1.2
unnamed: Q1.1 (E), Q2.1 (E), Q3.1 (E), Q4.1 (E), Q5.1 (E), Q8.2 (B), R10.1
unnamed: Q2.2 (B), R3.2
unnamed: Q3.2 (B), R6.2
unnamed: Q4.2 (B), R7.2
unnamed: Q6.2 (B), R12.2
unnamed: Q6.1 (E), Q7.1 (E), Q9.2 (B), R14.1
unnamed: Q8.3 (C), R16.1
unnamed: Q8.1 (E), Q9.1 (E), R17.2, R111.1
unnamed: Q9.3 (C), R15.1
unnamed: Q30.1 (E), Q31.1 (E), R63.2
unnamed: C46.1, Q31.2 (B), R66.2
unnamed: C44.2, Q31.3 (C), Q33.3 (C), Q34.3 (C), R64.1, R68.1, R82.2
unnamed: Q32.2 (B), R68.2
unnamed: C57.1, Q33.2 (B), R70.2, R71.2, R72.2
unnamed: C50.1, Q35.2 (B), R76.2
unnamed: C58.2, Q35.3 (C), Q38.3 (C), R78.2, R80.2, R81.1
unnamed: Q35.1 (E), Q36.1 (E), R74.1
unnamed: Q37.2 (B), R81.2
unnamed: C53.1, Q38.2 (B), R85.2, R86.2, R87.1
unnamed: Q39.2 (B), R96.2, R98.2
unnamed: C52.2, Q39.3 (C), Q42.3 (C), R99.2, R100.1
unnamed: Q40.2 (B), R100.2
unnamed: Q40.1 (E), Q41.1 (B), R101.1
unnamed: C55.1, Q42.2 (B), R102.2, R103.2
unnamed: Q43.2 (B), R111.2, R112.2
unnamed: Q43.3 (C), R110.1
unnamed: Q44.1 (C), R1.1, R2.2, R113.1
unnamed: R65.1, R66.3
unnamed: R66.1, R67.2
unnamed: R69.2, R70.1
unnamed: R75.2, R76.3
unnamed: R76.1, R77.1
unnamed: R84.2, R85.1
unnamed: R95.1, R96.1
unnamed: R96.3, R97.2
unnamed: R5.2, R6.1, R116.2
unnamed: R3.1, R4.2, R117.2

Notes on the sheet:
Does it have to be Ge?
Original schematic says -20V. Pictures show +20V. Makes more sense with +20V.
Top layer of J1 is A-Z and bottom layer is 1-22
+4.5V Regulator
Power up sequencing and power monitor
+12V Regulator
-2V Regulator

Board: 2 copper layers, 126 parts (0 on the bottom side), 84 nets, no tracks yet.

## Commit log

2026-04-03 Adding kicad projects.
    [HP_2116_Logic_Regulator.kicad_pcb, HP_2116_Logic_Regulator.kicad_sch, HP_2116_Memory_Regulator.kicad_pcb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]
2026-04-03 Missing regulator picture
2026-04-04 Added LTspice circuit.
2026-04-04 Updated some values in the logic regulator and re-generated the svg and created pdfs.
    [HP_2116_Logic_Regulator.kicad_sch]
2026-04-04 Update README with regulator schematics and procurement info
    Added schematics for logic and memory regulators, and updated component procurement status.
2026-06-14 Started to do a layout.
    [HP_2116_Logic_Regulator.kicad_pcb, HP_2116_Logic_Regulator.kicad_sch, HP_2116_Memory_Regulator.kicad_pcb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]
